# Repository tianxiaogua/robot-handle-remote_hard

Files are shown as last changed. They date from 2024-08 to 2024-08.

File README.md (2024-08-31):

# robot-handle-remote_hard
ESP32 遥控器 遥控手柄 兼容STREAM 同时可作为无线串口助手——硬件部分

# 分支命名
1、master 分支
master 为主分支，也是用于部署生产环境的分支，确保master分支稳定性， master 分支一般由develop以及hotfix分支合并，任何时间都不能直接修改代码

2、develop 分支
develop 为开发分支，始终保持最新完成以及bug修复后的代码，一般开发的新功能时，feature分支都是基于develop分支下创建的。

3、feature 分支
开发新功能时，以develop为基础创建feature分支。
分支命名: feature/ 开头的为特性分支， 命名规则: feature/user_module、 feature/cart_module

4、release分支
release 为预上线分支，发布提测阶段，会release分支代码为基准提测。当有一组feature开发完成，首先会合并到develop分支，进入提测时会创建release分支。如果测试过程中若存在bug需要修复，则直接由开发者在release分支修复并提交。当测试完成之后，合并release分支到master和develop分支，此时master为最新代码，用作上线。

5、hotfix 分支
分支命名: hotfix/ 开头的为修复分支，它的命名规则与feature分支类似。线上出现紧急问题时，需要及时修复，以master分支为基线，创建hotfix分支，修复完成后，需要合并到master分支和develop分支

参考：https://segmentfault.com/a/1190000037466445

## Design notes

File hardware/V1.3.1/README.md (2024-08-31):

# V1.1 LOG 2024.4.10

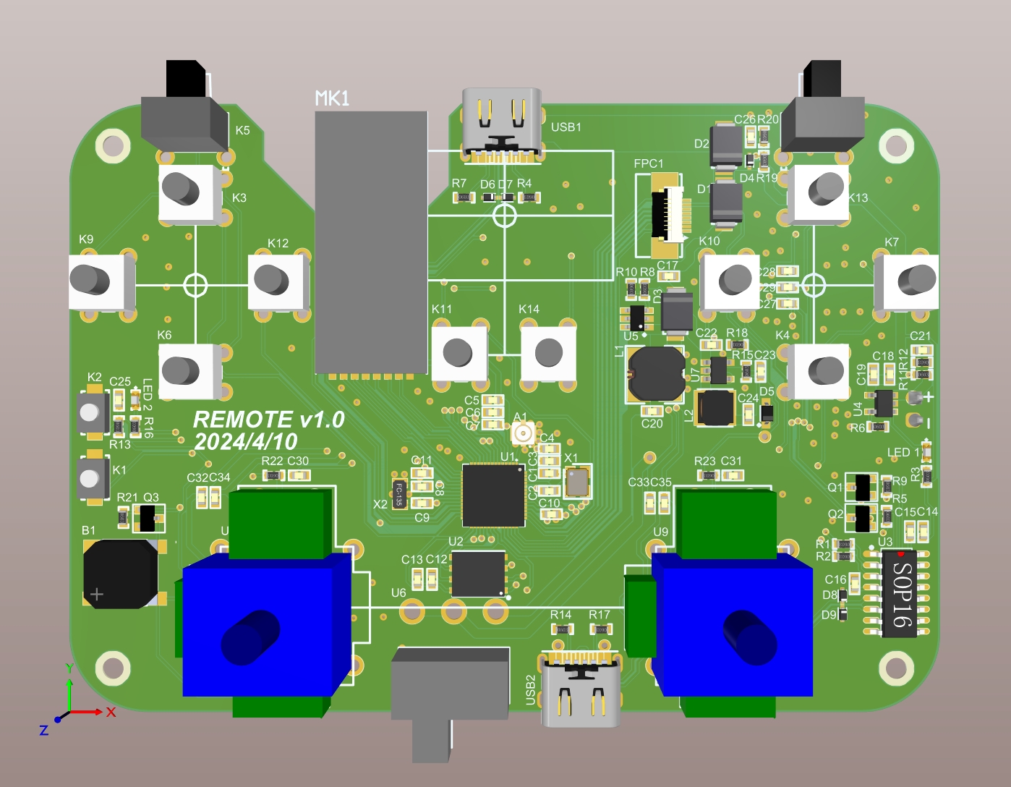
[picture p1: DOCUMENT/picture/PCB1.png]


## 设计实现

1、首版硬件主要实现了双USB，前面的是ESP32 USB，后面的USB用于调试；

2、实现基础的ESP32外围电路、下载电路、按键周围电路；

3、验证了摇杆封装；

4、为了实现更多的设备链接，增加了NRF2401模块用于实现2.4G射频前端；

5、增加了蜂鸣器；

6、电源部分使用3.7V升压方案，升压到稳定的5V，再降压到3.3V给系统电源使用；

7、可连接一块2.4寸TFT lCD屏幕；

8、确定了PCB形状和遥控器外形3D；

## 存在问题

1、前后两个USB过于累赘，下版本设计USB HUB芯片连接到一个USB口；

2、按键的手感不好，需要更改按键选型；

# V1.2 LOG 2024 6.22

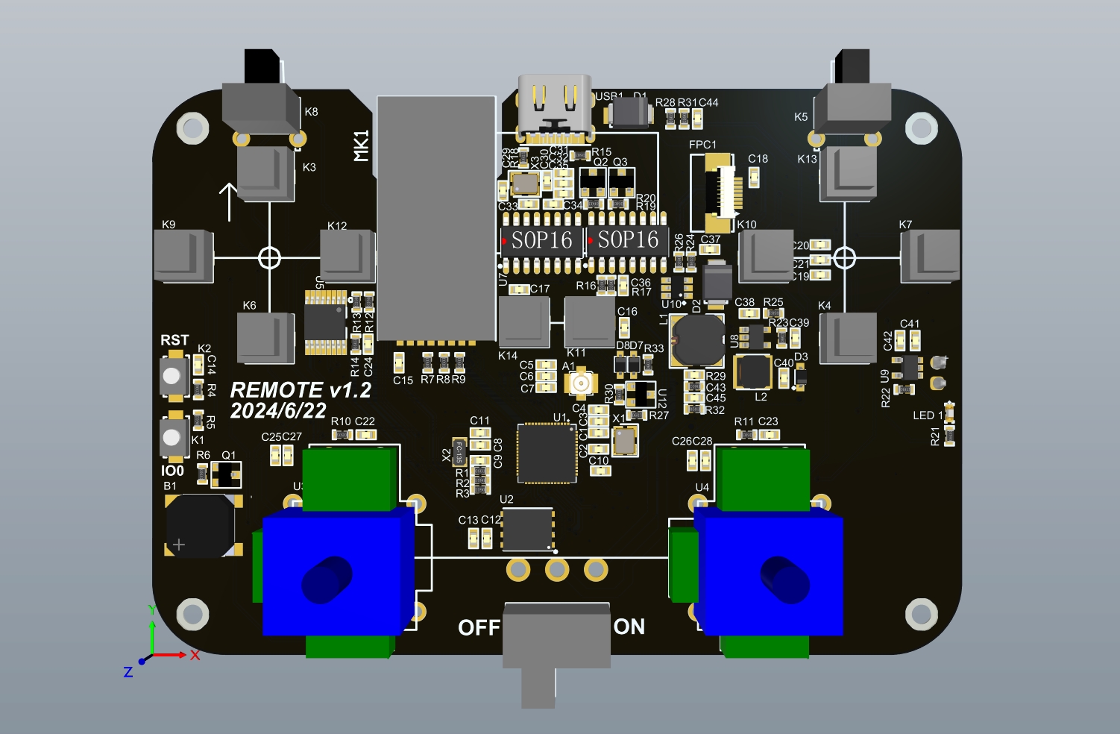
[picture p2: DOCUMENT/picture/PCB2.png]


## 设计实现

1、重新设计了按键选型；

2、添加USB HUB芯片可以是实现两个USB连接在一个USB口上；

3、增加了IO拓展芯片。

## 存在问题

1、2.4G通信模组实际使用中属于实际冗余，下一个版本需要去掉；

2、USB上拉引脚接错了，需要接在USB DP上；

3、IO拓展芯片的最好上拉值应设置在4.7K；

4、按键的引脚分配存在问题，不可以使用ESP32的某些引脚，下版本将这些引脚重新设置到IO拓展引脚上，部分引脚需要重新分配；

5、屏幕的位置比较难安装，屏幕排线需要延长，需要单独设计一块延长排线的转接板；

# V1.3 LOG 2024.8.18

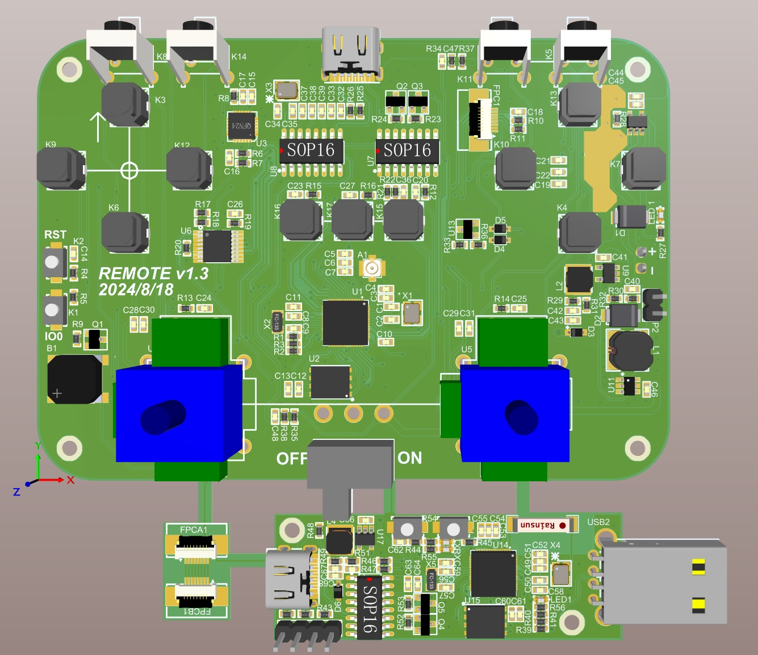
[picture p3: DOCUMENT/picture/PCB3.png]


## 设计实现

1、增加陀螺仪加速器芯片；

2、增加两个肩键在扫描电路上、增加CHA按键连接在ESP32 IO；

3、开机电路增加EN排针插座；

4、增加接收电路部分和排线电路；

5、重新布局布线；

## 存在问题

1、SPI1_CS放在IO拓展芯片上会降低SPI 通信速度，下版本将SPI1_CS 换到ESP32 GPIO7 ，将原本USB KEY换到 IO 拓展引脚；

2、KEY_SELECT和KEY_START按键的外部电路错误，下一版本需要将IO引脚上拉，按键另一端连接到GND；

3、MPU6050上拉电阻修改至2K；

4、PCA9557 IIC上拉修改至2K，IO0上拉修改至4.7K；

# V1.3.1 LOG 2024.8.29

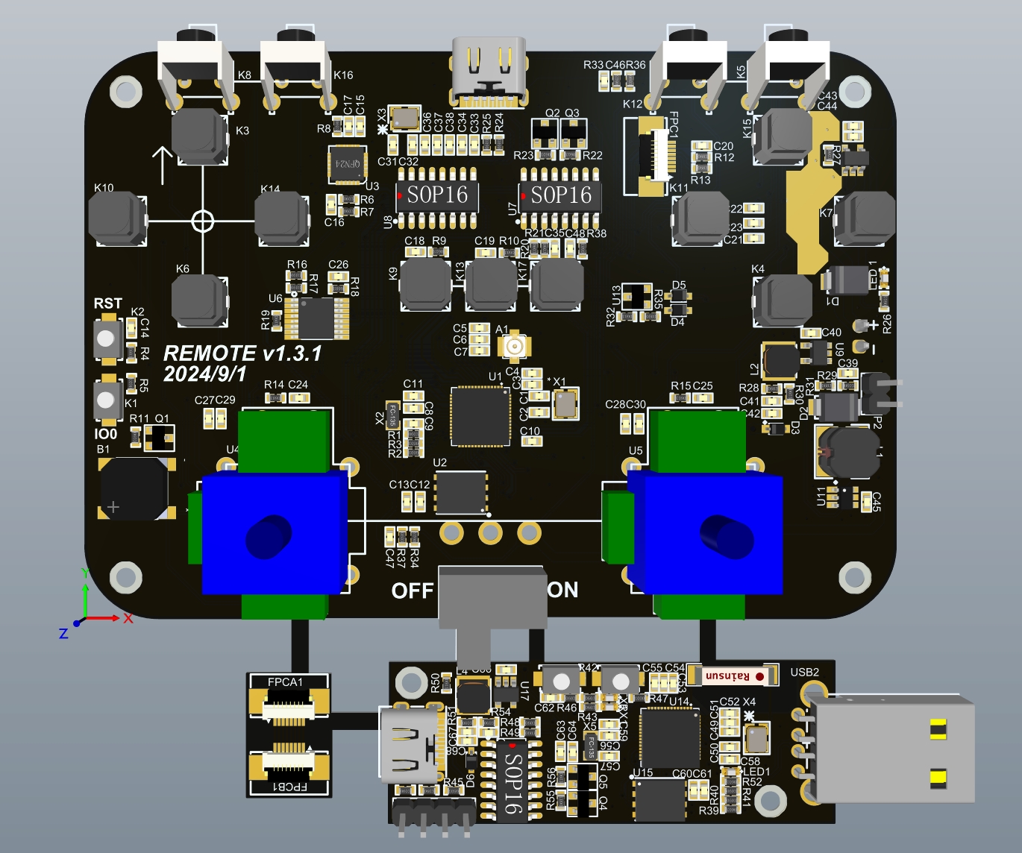
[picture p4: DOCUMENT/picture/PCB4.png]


## 设计实现

1、修改按键上拉和接地；

2、调换key_usb和SPI_CS引脚；

## 存在问题

暂无

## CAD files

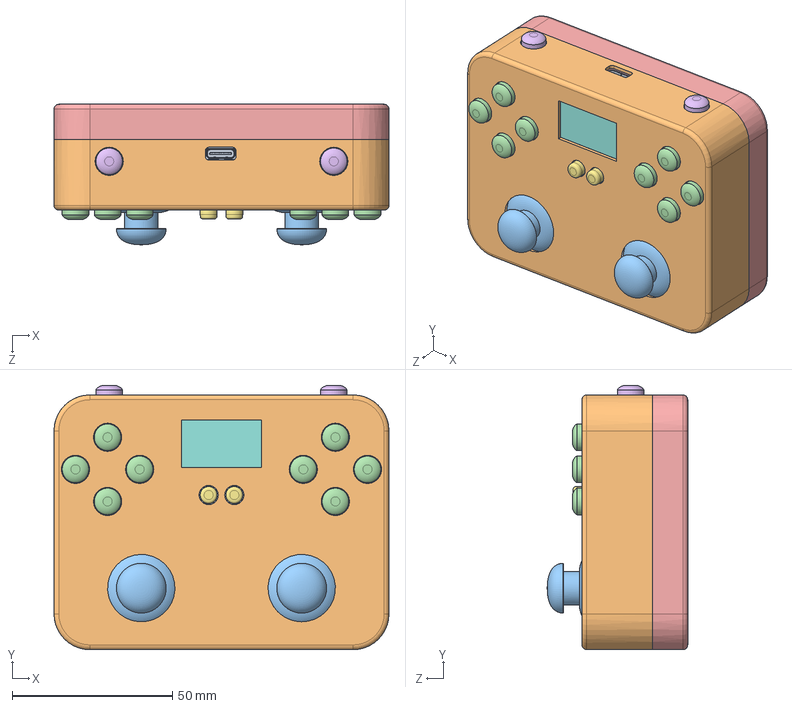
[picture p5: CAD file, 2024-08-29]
3D/V1/装配体2.SLDASM
104.4 x 82.4 x 43.8 mm
PCB2
上盖
摇杆 x 2
按钮 x 8
后盖
按钮2 x 2
按钮3 x 2
屏幕

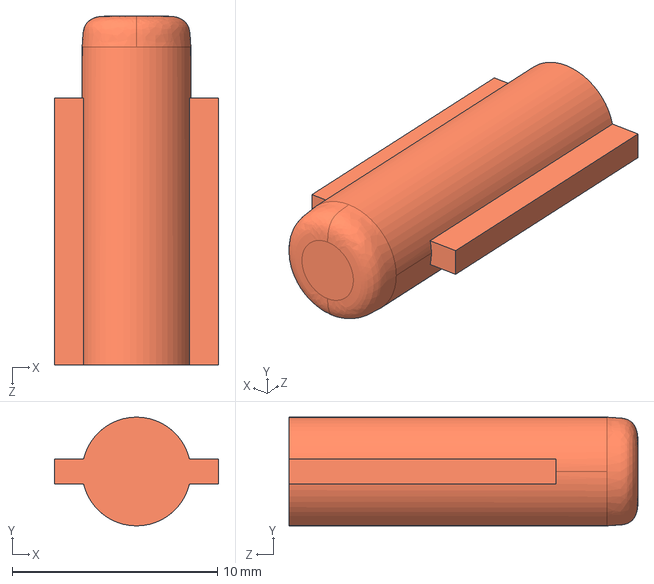
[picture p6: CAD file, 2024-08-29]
3D/V1/3D 打印/按钮3X2.STEP
8.00 x 5.30 x 17.0 mm

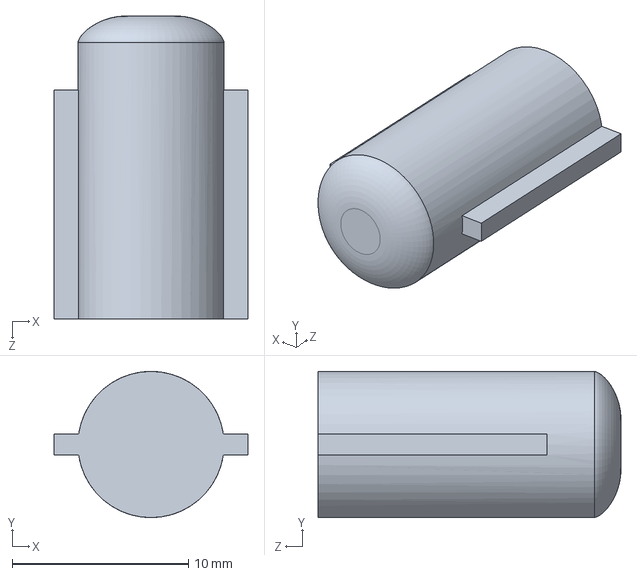
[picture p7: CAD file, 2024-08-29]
3D/V1/按钮.SLDPRT
11.0 x 8.30 x 17.2 mm

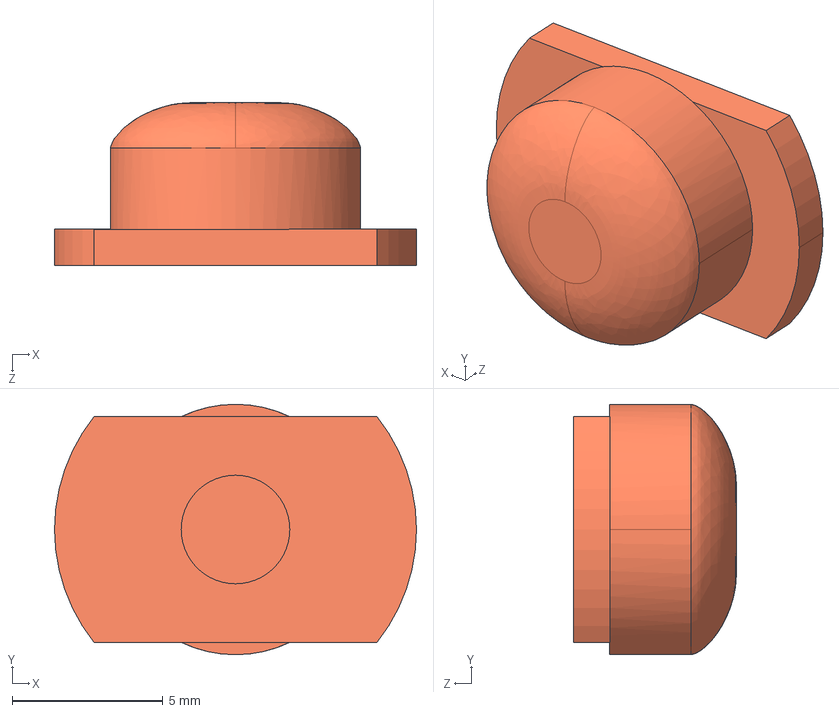
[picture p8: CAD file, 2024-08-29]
3D/V1/3D 打印/按钮2X2.STEP
12.0 x 8.30 x 5.40 mm

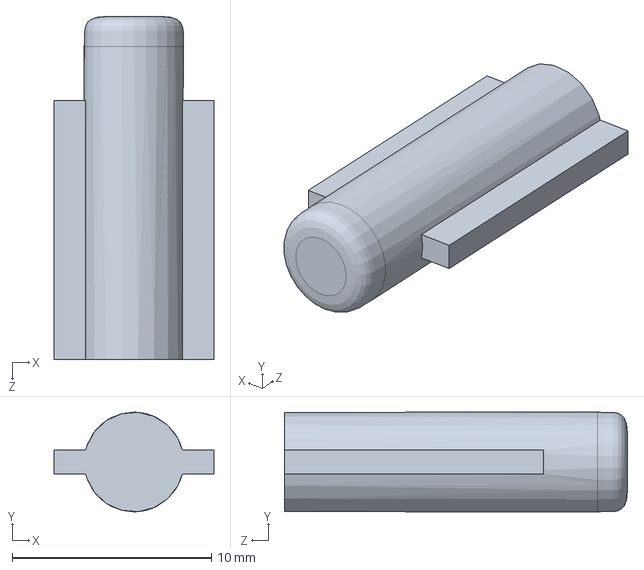
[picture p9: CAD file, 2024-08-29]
3D/V1/按钮3.SLDPRT
8.00 x 5.00 x 17.2 mm

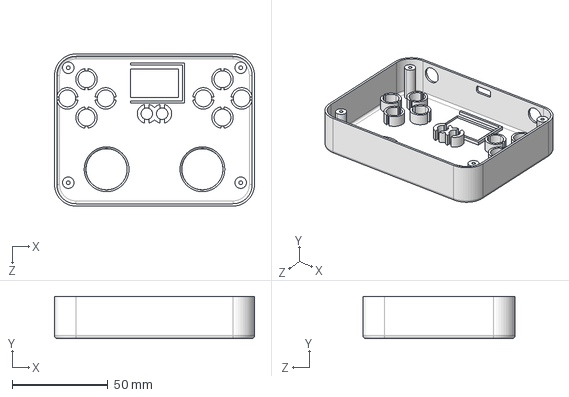
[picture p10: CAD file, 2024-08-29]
3D/V1/3D 打印/上盖X1.STEP
104.4 x 22.0 x 79.4 mm

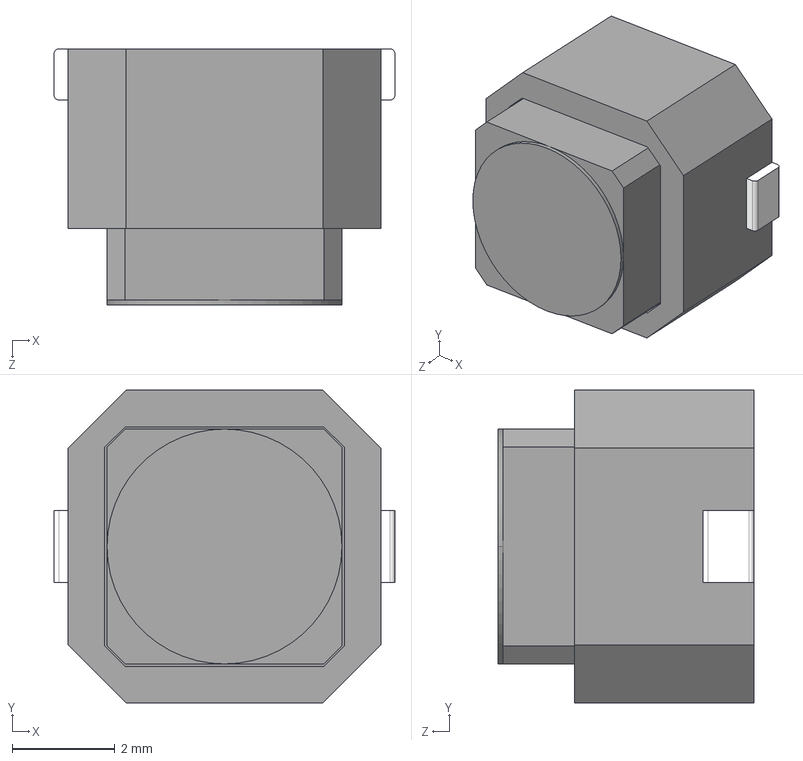
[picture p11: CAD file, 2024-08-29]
3D/V1/按键.STEP
6.65 x 6.10 x 5.00 mm

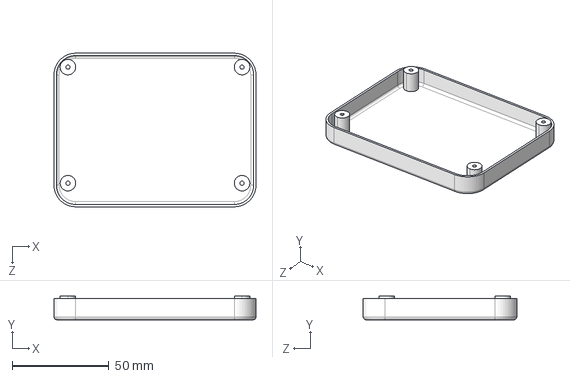
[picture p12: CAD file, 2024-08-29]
3D/V1/3D 打印/后盖X1.STEP
104.4 x 12.2 x 79.4 mm

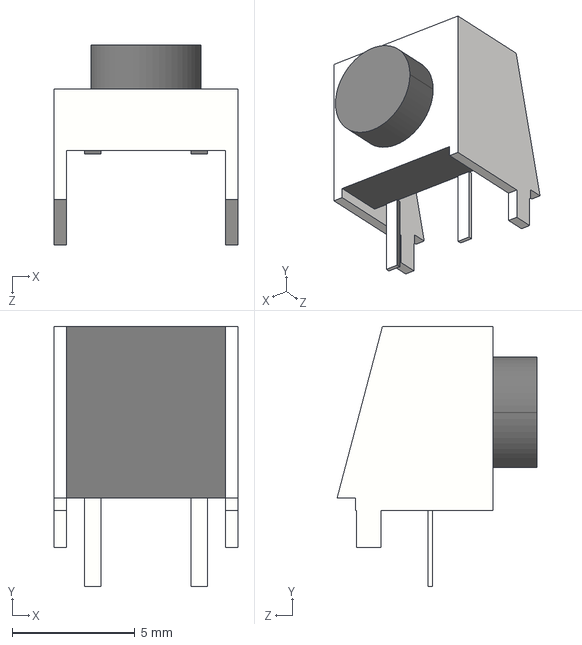
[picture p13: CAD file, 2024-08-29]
3D/V1/侧按钮.STEP
7.50 x 10.6 x 8.15 mm

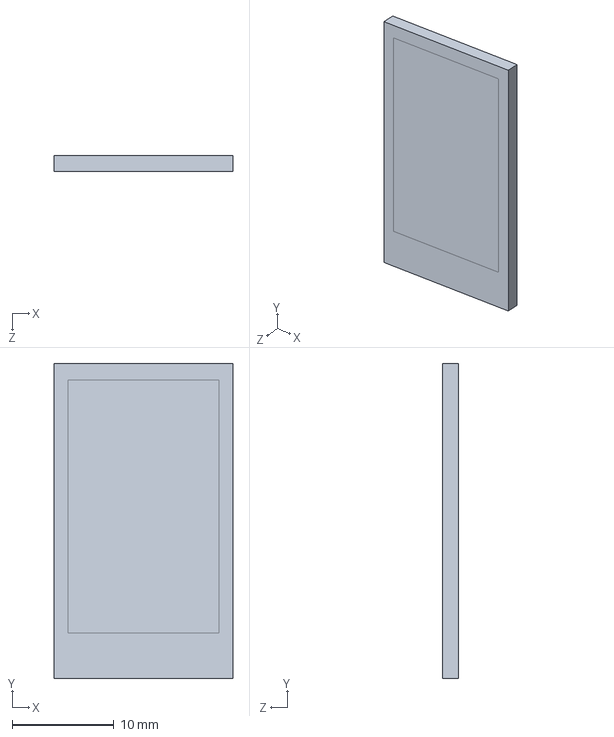
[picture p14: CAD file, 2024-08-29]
3D/V1/屏幕.SLDPRT
17.6 x 31.0 x 1.60 mm

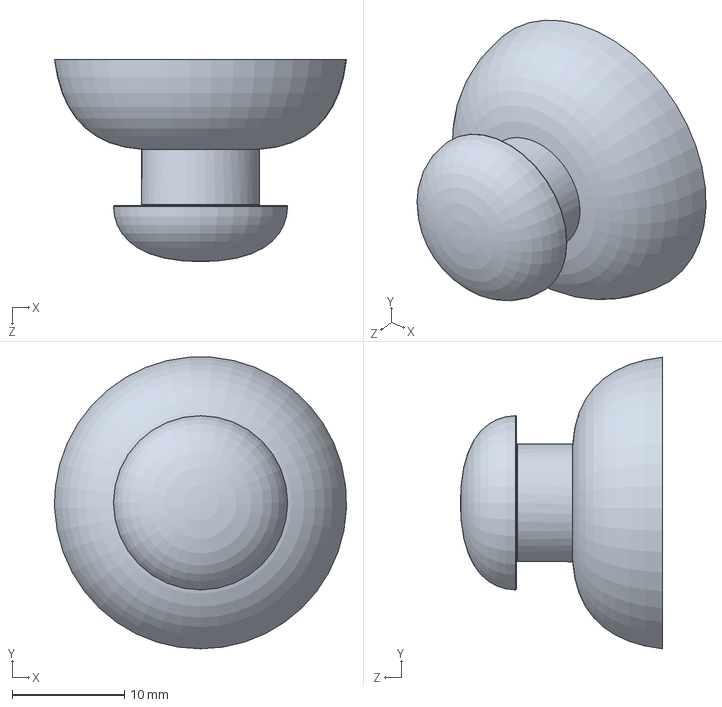
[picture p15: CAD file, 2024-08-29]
3D/V1/摇杆.SLDPRT
26.0 x 26.0 x 18.0 mm

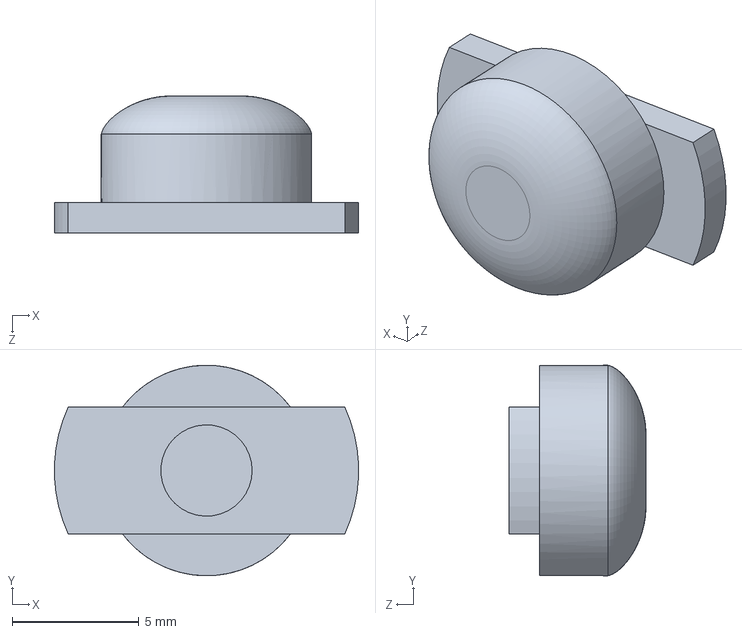
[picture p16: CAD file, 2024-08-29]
3D/V1/按钮2.SLDPRT
12.0 x 8.30 x 5.40 mm

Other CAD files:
3D/V1/3D 打印/按钮1X8.STEP
3D/V1/上盖.SLDPRT
3D/V1/后盖.STEP
3D/V1/3D 打印/上盖X1.SLDPRT
3D/V1/3D 打印/上盖X1.STL
3D/V1/3D 打印/后盖X1.SLDPRT
3D/V1/3D 打印/后盖X1.STL
3D/V1/3D 打印/按钮1X8.SLDPRT
3D/V1/3D 打印/按钮1X8.STL
3D/V1/3D 打印/按钮2X2.SLDPRT
3D/V1/3D 打印/按钮2X2.STL
3D/V1/3D 打印/按钮3X2.SLDPRT
3D/V1/3D 打印/按钮3X2.STL
3D/V1/侧按钮.SLDPRT
3D/V1/后盖.SLDPRT
3D/V1/按键.SLDPRT

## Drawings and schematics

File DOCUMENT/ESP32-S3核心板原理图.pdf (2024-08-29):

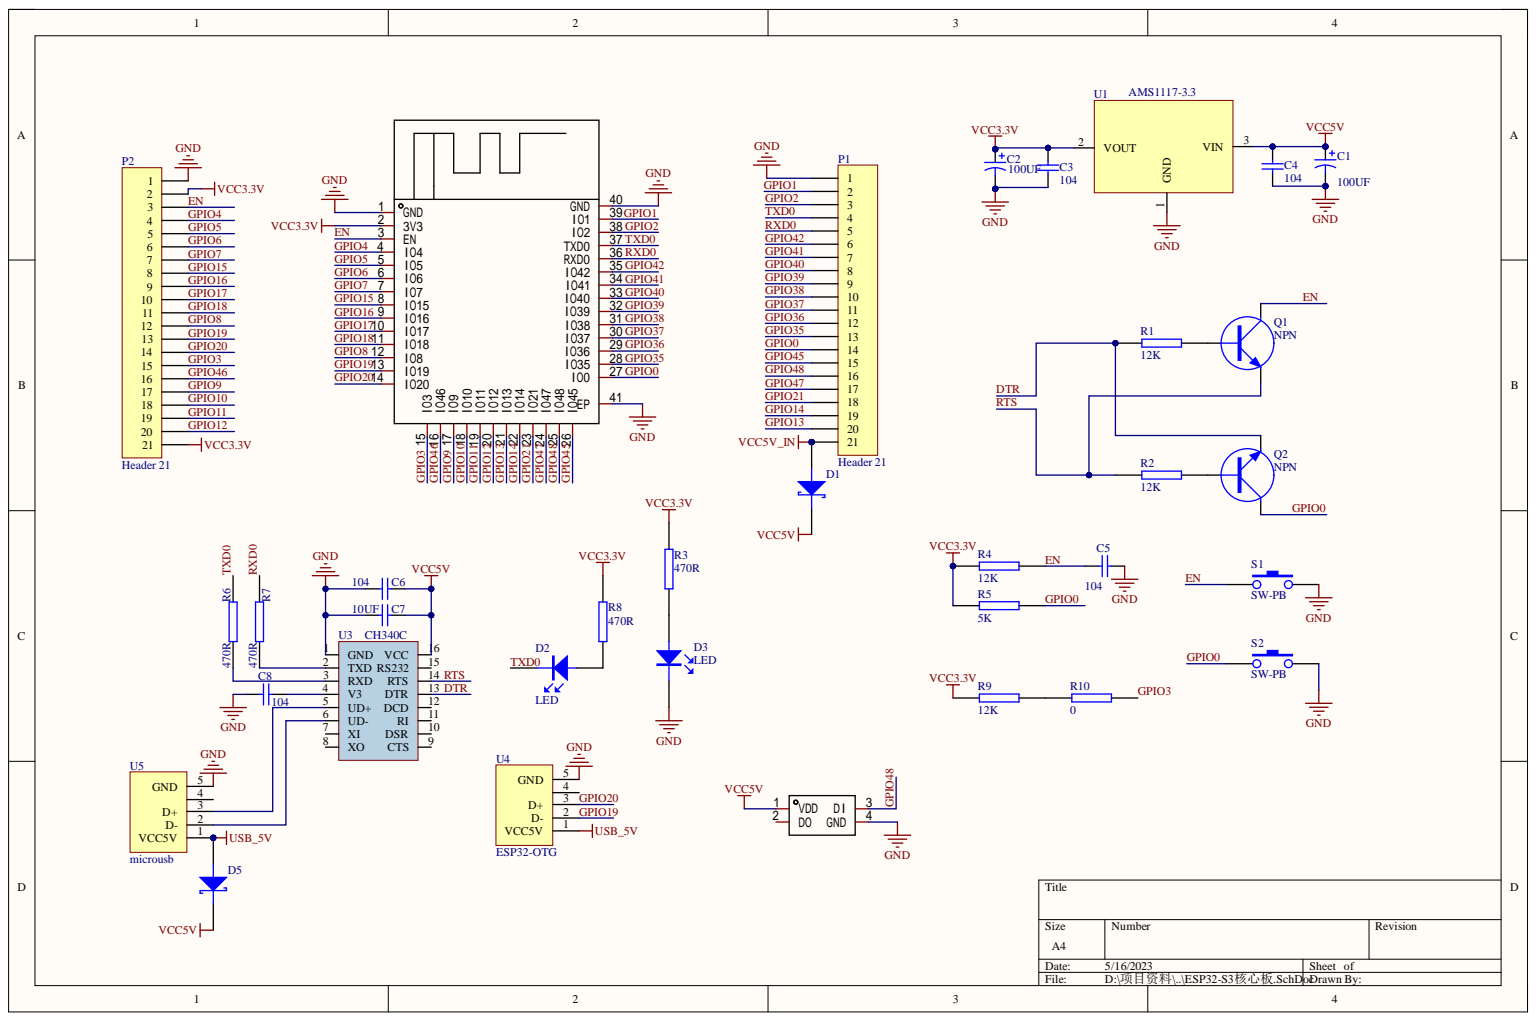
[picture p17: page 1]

Comment | Description | Designator | Footprint | LibRef | Quantity
| Polarized Capacitor (Radial) | C1 | 1206 | Cap Pol1 | 1
100UF | Polarized Capacitor (Radial) | C2 | 钽电容J107 | Cap Pol1 | 1
104 | Capacitor | C3, C4, C5, C6, C8 | C0402 | Cap | 5
Cap | Capacitor | C7 | 1206 | Cap | 1
| Schottky Diode | D1, D5 | D0603 | DIODE SCHOTTKY | 2
LED | | D2, D3 | 0603D | LED | 2
XL-5050RGBC-WS2812B | | D4 | LED-SMD_L5.0-W5.0-P3.20-LS5.4-TL | XL-5050RGBC-WS2812B | 1
Header 21 | Header, 20-Pin | P1, P2 | HDR1X21 | Header 21 | 2
NPN | NPN Transistor | Q1, Q2 | SOT-23 | NPN | 2
12K | | R1, R2, R4, R9 | R0402 | RES2 | 4
470R | | R3, R6, R7, R8 | R0402 | RES2 | 4
5K | | R5 | R0402 | RES2 | 1
0 | | R10 | R0402 | RES2 | 1
SW-PB | | S1, S2 | button | SW-PB | 2
AMS1117-3.3 | | U1 | SOT223 | AMS1117-3.3 | 1
ESP32-S3-WROOM-1-N8 | | U2 | ESP32-S3 W1 | ESP32-S3-WROOM-1-N8 | 1
CH340C | | U3 | SO-16_M | CH340 | 1
ESP32-OTG | | U4 | USB_T | microusb | 1
microusb | | U5 | USB_T | microusb | 1

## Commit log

2024-08-29 [ADDLOG] 1、添加V1.3.1版本硬件
    [PCB.PcbDoc, Sheet0-mcu.SchDoc, Sheet1-control.SchDoc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]
2024-08-31 更细readme
2024-08-31 [CHGLOG] 1、更新1.3.1版本，修复按键问题、调换USB按键和spi片选；
    [Sheet0-mcu.SchDoc, Sheet1-control.SchDoc, Sheet2-USB.SchDoc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]
2024-08-31 [CHGLOG] 1、更新生产文件；
